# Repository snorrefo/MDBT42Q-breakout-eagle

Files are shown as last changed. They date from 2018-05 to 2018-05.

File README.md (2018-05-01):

# MDBT42Q-breakout-eagle
Eagle files for making a breakout board for Raytac's MDBT42Q - nRF52832 based BLE module

Ordered MDBT42Q modules from [Tinysine](https://www.tinyosshop.com/mdbt42-ble-module), due to low shipping to Norway. $7.95 each, plus $4 shipping to Norway. Alternative: [Seed](https://www.seeedstudio.com/MDBT42Q-nRF52832-based-BLE-module-p-2736.html) 

Uploaded MDBT42Q.brd and ordered board from [OSH Park](https://oshpark.com/shared_projects/iggYdmAZ). Link contains shared project, ready for order. $9.80 per batch of three.

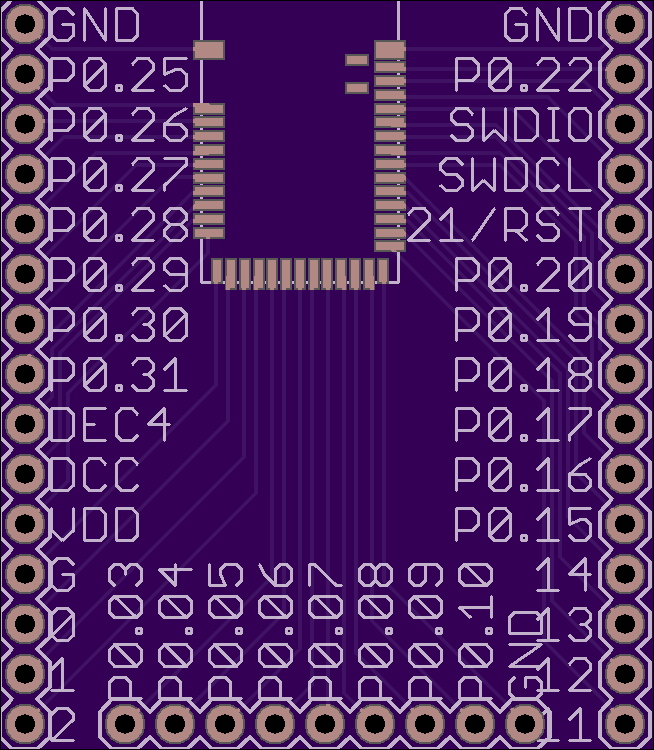
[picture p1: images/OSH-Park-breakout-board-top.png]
Breakout board


Uploaded MDBT42Q.brd and ordered solder stencil and acrylic jig set from [OSH Stencils](https://www.oshstencils.com/) for 10 $ + 5 $ shipping to Norway. Stencil Polyimide Film 3mil (0.003").

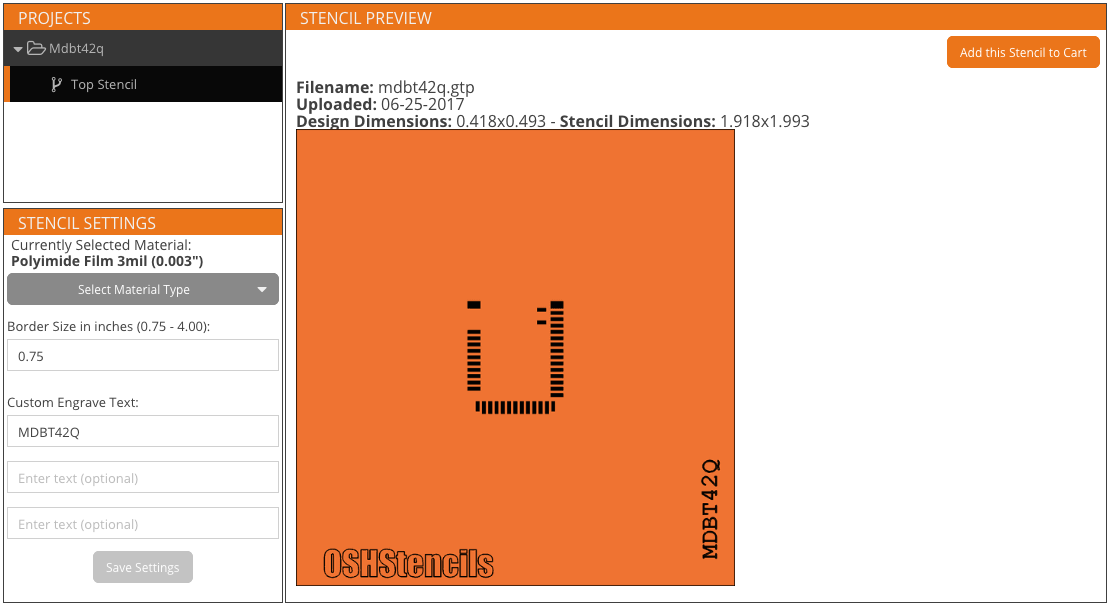
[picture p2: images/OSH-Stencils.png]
Solder stencil


Used lead-free solder paste from [SparkFun/Chip Quik](https://www.sparkfun.com/products/12878).

After applying solder paste using the stencil, jig set and solder paste spreader (included in the jig set), the MDBT42Q module was placed gently on top of the solder and board. It doesn't matter much that the solder is smeared a bit, as the reflow will draw the solder to the solder pads. 

The board was placed in an old springform cake tin, and placed on a kitchen stove plate to reflow the solder. Turning the plate on, I used a digital cooking thermometer placed under some tin foil to monitor the cake tin temperature. My thermometer read ca. 223 deg C when the solder paste had reflowed properly. See solder paste data sheet for recommended reflow temperature profile (max 249 deg C). When the solder had reflowed properly, the cake tin was removed from the hot plate to cool. The result:

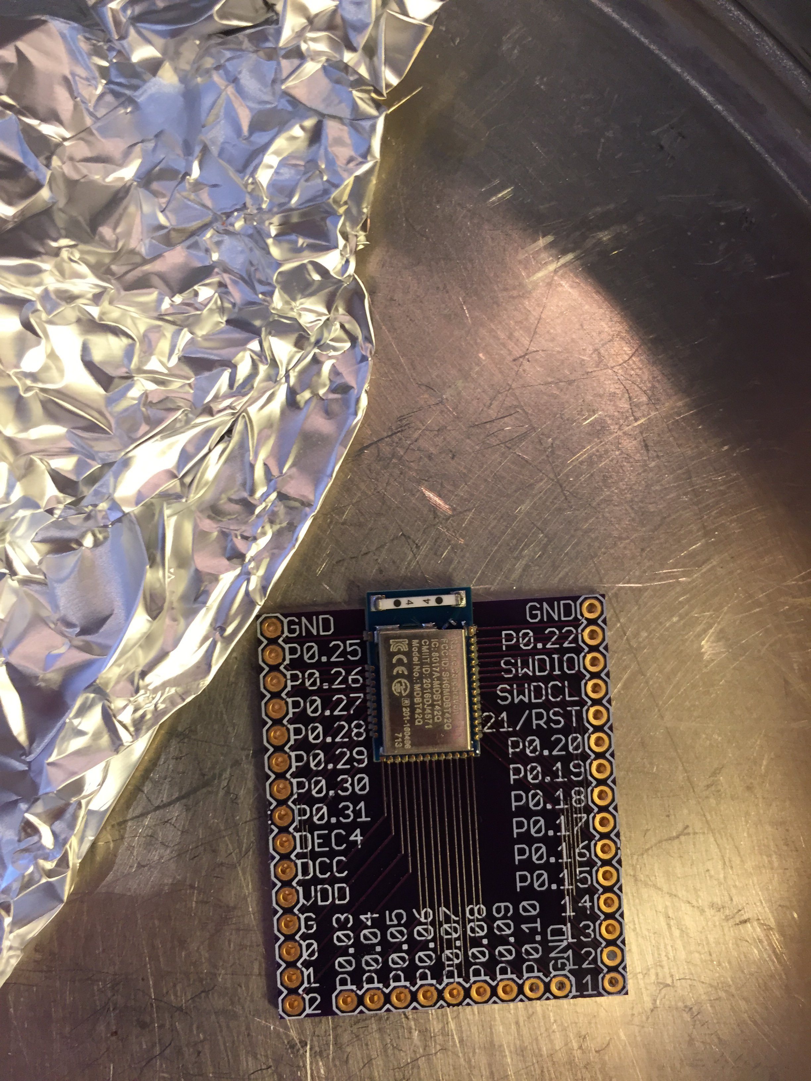
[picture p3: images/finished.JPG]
Finished reflow


Using a JTAG programmer, such as the one included on Nordic's [nRF52 Developer Kit](https://www.nordicsemi.com/eng/Products/Bluetooth-low-energy/nRF52-DK), I was able to program the MDBT42Q module. More on that later. See for example 

https://learn.sparkfun.com/tutorials/nrf52832-breakout-board-hookup-guide

https://devzone.nordicsemi.com/f/nordic-q-a/14058/external-programming-using-nrf52-dk

Connecting the nRF52 DK to the MDBT42Q:

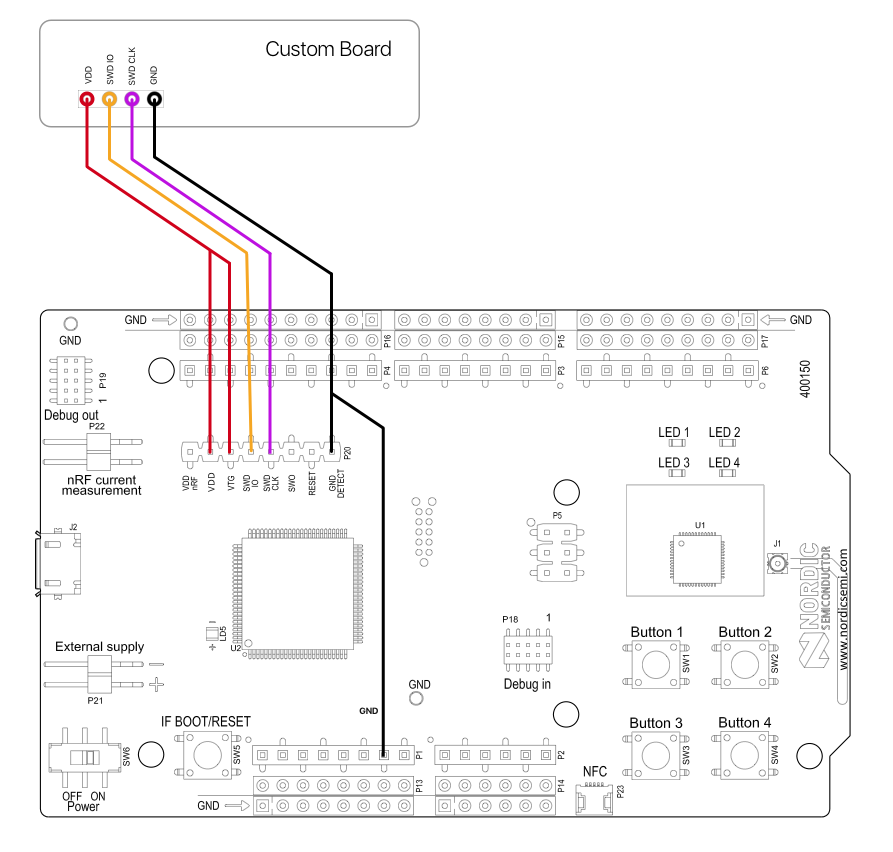
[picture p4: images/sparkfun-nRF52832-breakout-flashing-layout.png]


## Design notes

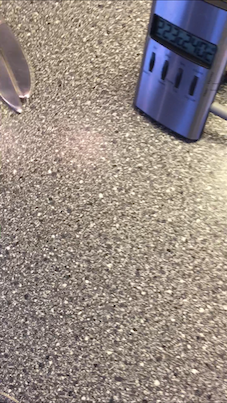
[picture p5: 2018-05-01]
images/catemp.png

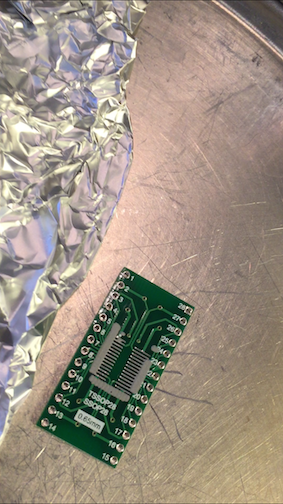
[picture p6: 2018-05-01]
images/reflowbefore.png

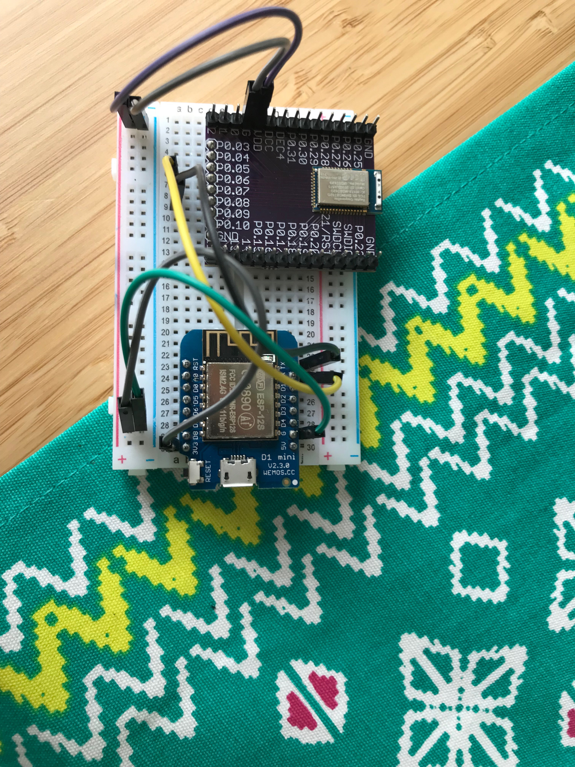
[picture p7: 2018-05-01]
images/mounted.JPG

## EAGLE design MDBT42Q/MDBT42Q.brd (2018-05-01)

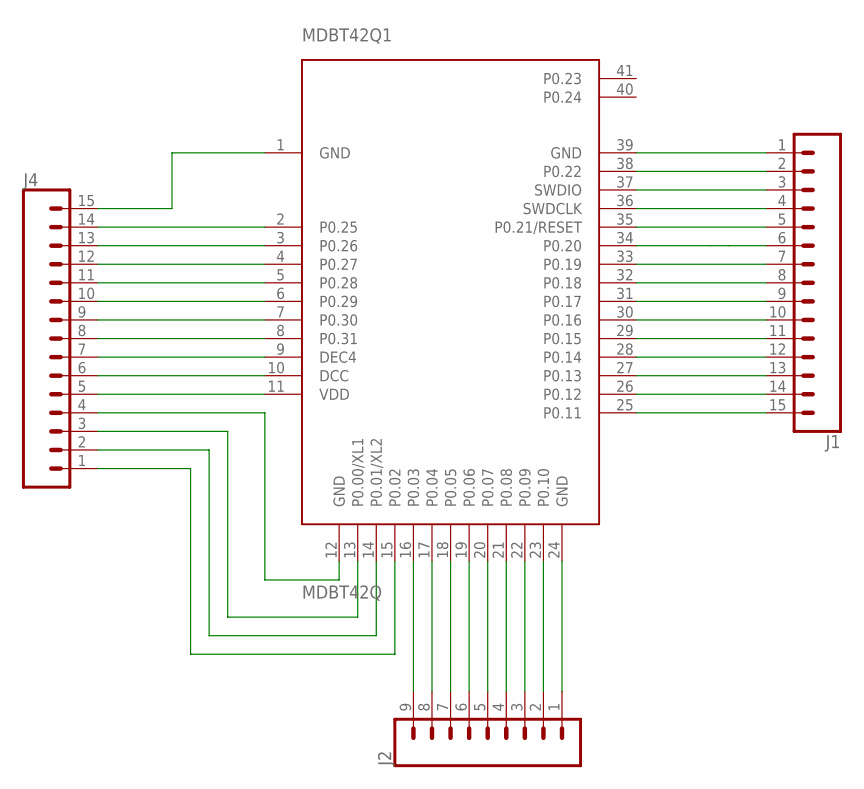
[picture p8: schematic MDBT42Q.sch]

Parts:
J1, J4: CONN_15; 1X15
J2: CONN_09; 1X09
MDBT42Q1: MDBT42Q

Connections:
unnamed: J4.15, MDBT42Q1.1 (GND)
unnamed: J4.14, MDBT42Q1.2 (P0.25)
unnamed: J4.13, MDBT42Q1.3 (P0.26)
unnamed: J4.12, MDBT42Q1.4 (P0.27)
unnamed: J4.11, MDBT42Q1.5 (P0.28)
unnamed: J4.10, MDBT42Q1.6 (P0.29)
unnamed: J4.9, MDBT42Q1.7 (P0.30)
unnamed: J4.8, MDBT42Q1.8 (P0.31)
unnamed: J4.7, MDBT42Q1.9 (DEC4)
unnamed: J4.6, MDBT42Q1.10 (DCC)
unnamed: J4.5, MDBT42Q1.11 (VDD)
unnamed: J4.4, MDBT42Q1.12 (GND)
unnamed: J4.3, MDBT42Q1.13 (P0.00/XL1)
unnamed: J4.2, MDBT42Q1.14 (P0.01/XL2)
unnamed: J4.1, MDBT42Q1.15 (P0.02)
unnamed: J2.9, MDBT42Q1.16 (P0.03)
unnamed: J2.8, MDBT42Q1.17 (P0.04)
unnamed: J2.5, MDBT42Q1.20 (P0.07)
unnamed: J2.6, MDBT42Q1.19 (P0.06)
unnamed: J2.7, MDBT42Q1.18 (P0.05)
unnamed: J2.4, MDBT42Q1.21 (P0.08)
unnamed: J2.3, MDBT42Q1.22 (P0.09)
unnamed: J2.2, MDBT42Q1.23 (P0.10)
unnamed: J2.1, MDBT42Q1.24 (GND)
unnamed: J1.15, MDBT42Q1.25 (P0.11)
unnamed: J1.14, MDBT42Q1.26 (P0.12)
unnamed: J1.13, MDBT42Q1.27 (P0.13)
unnamed: J1.12, MDBT42Q1.28 (P0.14)
unnamed: J1.11, MDBT42Q1.29 (P0.15)
unnamed: J1.10, MDBT42Q1.30 (P0.16)
unnamed: J1.9, MDBT42Q1.31 (P0.17)
unnamed: J1.8, MDBT42Q1.32 (P0.18)
unnamed: J1.7, MDBT42Q1.33 (P0.19)
unnamed: J1.6, MDBT42Q1.34 (P0.20)
unnamed: J1.5, MDBT42Q1.35 (P0.21/RESET)
unnamed: J1.4, MDBT42Q1.36 (SWDCLK)
unnamed: J1.3, MDBT42Q1.37 (SWDIO)
unnamed: J1.2, MDBT42Q1.38 (P0.22)
unnamed: J1.1, MDBT42Q1.39 (GND)

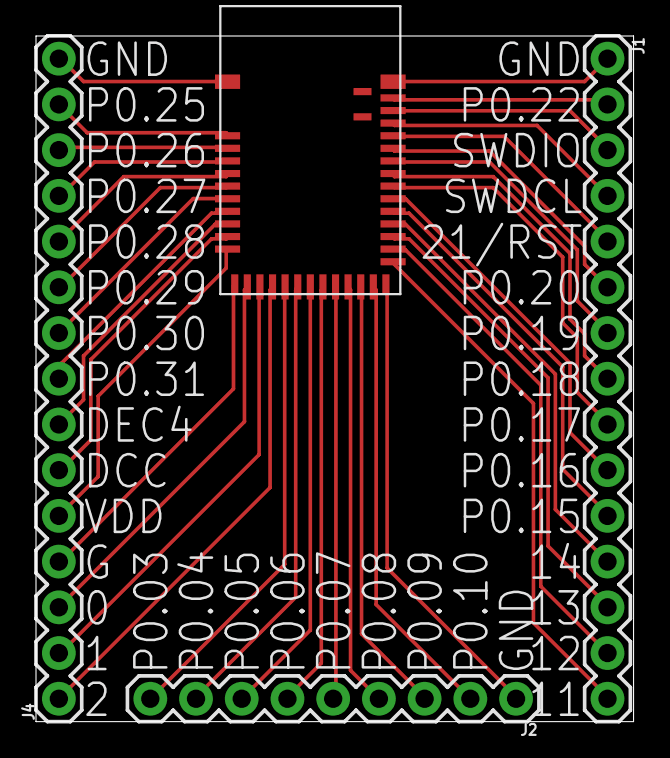
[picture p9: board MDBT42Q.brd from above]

Board: 2 copper layers, 33.2 x 38.1 mm, 4 parts (0 on the bottom side), 39 nets.

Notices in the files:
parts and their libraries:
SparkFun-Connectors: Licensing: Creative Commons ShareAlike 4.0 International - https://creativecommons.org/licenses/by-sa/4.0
